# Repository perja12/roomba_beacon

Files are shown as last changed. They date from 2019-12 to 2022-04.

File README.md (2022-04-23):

# IR Beacon for Roomba

Quick links: [Schematic](https://perja12.github.io/roomba_beacon/kicad/ir_beacon/ir_beacon.pdf) | [Interactive BOM](https://perja12.github.io/roomba_beacon/kicad/ir_beacon/bom/ibom.html)

This project describes an IR beacon that can be used with certain Roomba vacuum cleaners. The beacon can be used to prevent the vacuum cleaner from entering a room or other off-limit zones. The vacuum cleaner will simply turn around when it receives the infrared light emitted from the beacon.

The project is inspired by a similar project from http://gregthielen.me/blogstuff/2017/06/27/roomba-virtual-wall/ and the timings for IR LED is taken directly from that page.

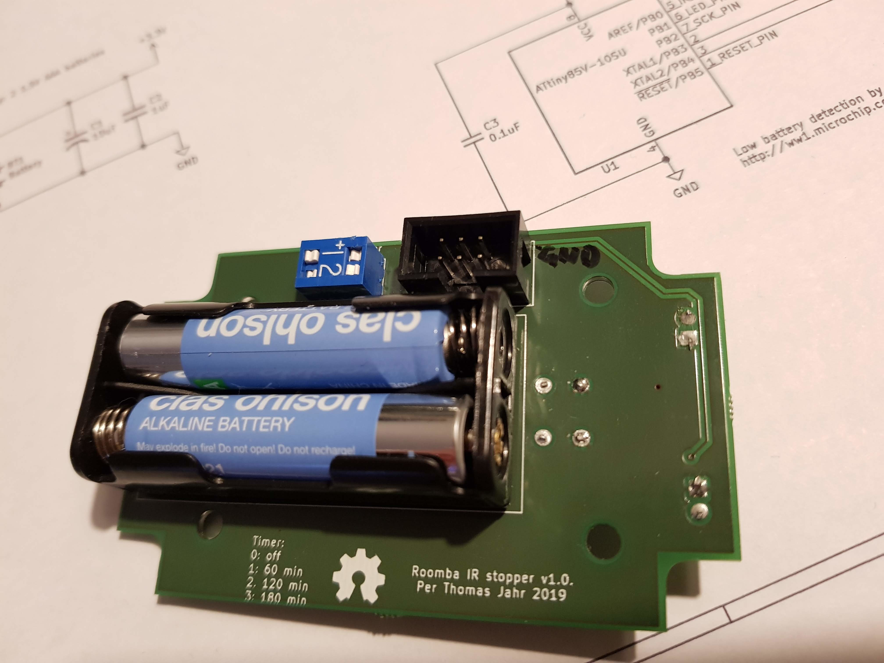
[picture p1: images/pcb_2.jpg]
PCB side 2


## Design

The circuit itself is simple enough; when the push button is pressed, the IR LED will flash in a given pattern. To save battery the duration is limited to one hour (configurable). In addition there is a green indicator LED that will flash once when the device is turned on and twice when turned off.

An ATtiny85V is used without any voltage regulator as it can operate with a voltage from 1.8 to 5.5V. The device is powered by two AAA alkaline batteries and the battery holder is soldered to the PCB. As the ATtiny85 have maximum current of 40 mA per pin and the IR LED (Vishay TSAL4000) has a forward current of 100 mA, we will need a transistor (MMBT3904) to switch the IR LED.

# Power consumption

There are two modes of operation:

1) Sleep mode: the IR LED is off and the MCU is in deep sleep. The current consumption is a couple of uA.

2) The average current consumption during active mode (when blinking the IR LED) is about 3.3 mA and can be lowered by using SLEEP_IDLE to save power and wake up when 132 ms have passed.

# Push button on/off switch

The circuit uses a power latch implemented by using special instructions that skips resetting a particular variable to zero during reset (see the _power_ variable in the code).  The push button is connected to the RESET pin and when pressed it will reset the MCU. The setup function toggles the _power_ variable and the circuit either goes to sleep or starts blinking the LED. With such a design it is important to have low sleep current. The solution is described here: http://www.technoblogy.com/show?VOO.

# Configurable on-duration

Depending on the route the vacuum cleaner chooses one can decide how many hours the device will be on. The user can configure this by setting two DIP switches. The duration is measured by using the number of milliseconds since the device was reset. The accuracy of this timer is not very good and can be off by several minutes. But for this purpose it works well enough.

# Detect low battery (not implemented)

On start up the indicator LED will blink rapidly if it is time to replace the batteries (around 2V). This is implemented by setting the internal reference voltage as ADC input and the target VCC as the ADC reference. The solution is described in this application note from Microchip: http://ww1.microchip.com/downloads/en/Appnotes/00002447A.pdf

# How to build

Install the ATTinyCore and use the following settings in the Arduino IDE

* Uses ATTinyCore: https://github.com/SpenceKonde/ATTinyCore
* 8 MHz internal clock
* B.O.D. disabled to save power

There is also a Makefile that uses [arduino-cli](https://www.arduino.cc/pro/cli).

# Enclosure

The PCB is designed so that it fits the Hammond 1591 ABS multipurpose enclosure and can be mounted directly without any standoffs. Only three additional holes are needed. Using one of the transparent boxes makes it easy to see where to drill. Note that there is a slight angle on the sides so the box wont stand exactly at 90 degrees, but close enough.

# Improvements

List of improvements that can be done:

* Clean up the layout and make it more compact.
* Replace delay in code with timers.
* Blink the LED now and then to show that it is on.

# Images

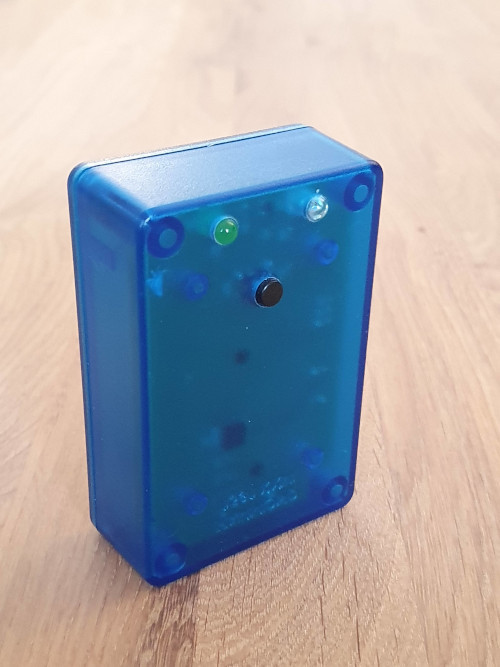
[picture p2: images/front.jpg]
Front

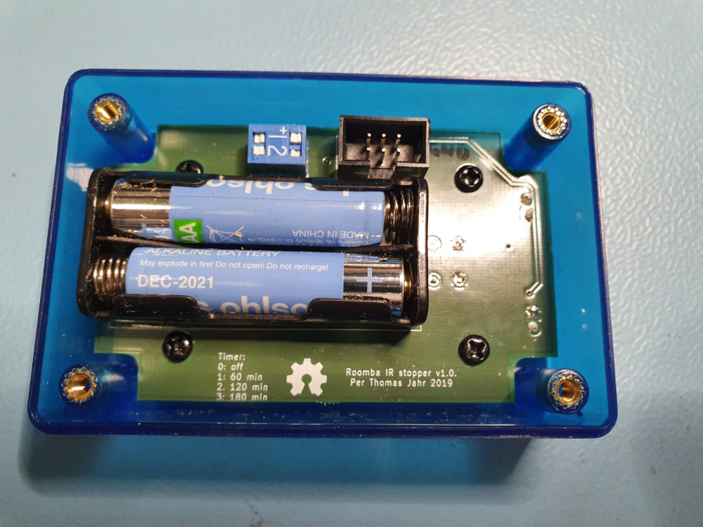
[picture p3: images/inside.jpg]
Inside enclousre

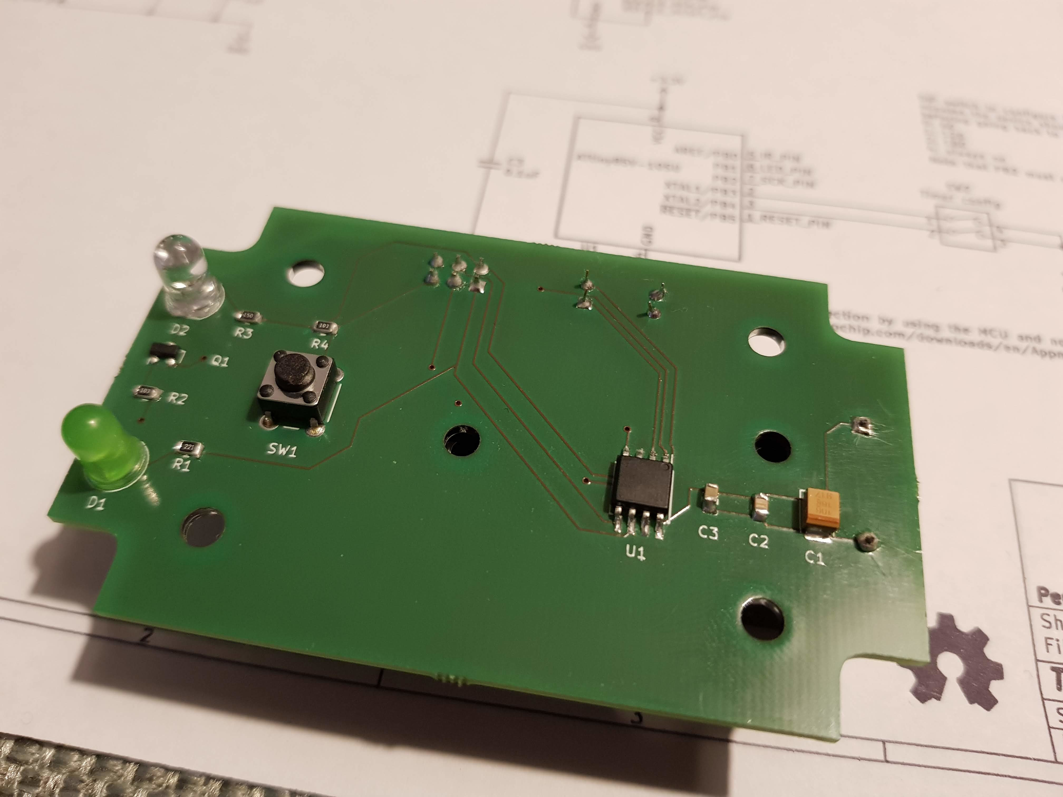
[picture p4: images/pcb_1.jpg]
PCB side 1


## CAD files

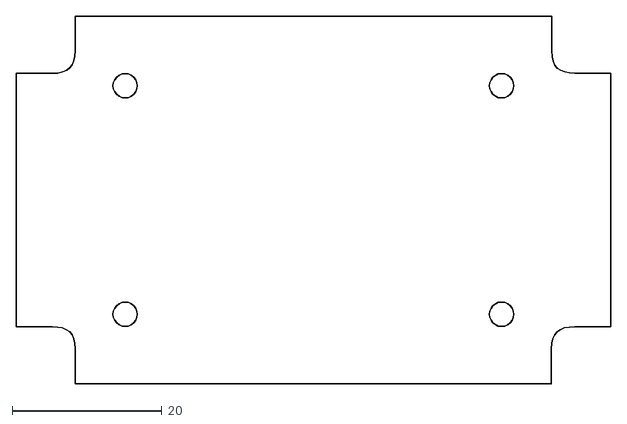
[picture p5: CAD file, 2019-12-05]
kicad/ir_beacon/1591_correct.dxf
79.4 x 49.1

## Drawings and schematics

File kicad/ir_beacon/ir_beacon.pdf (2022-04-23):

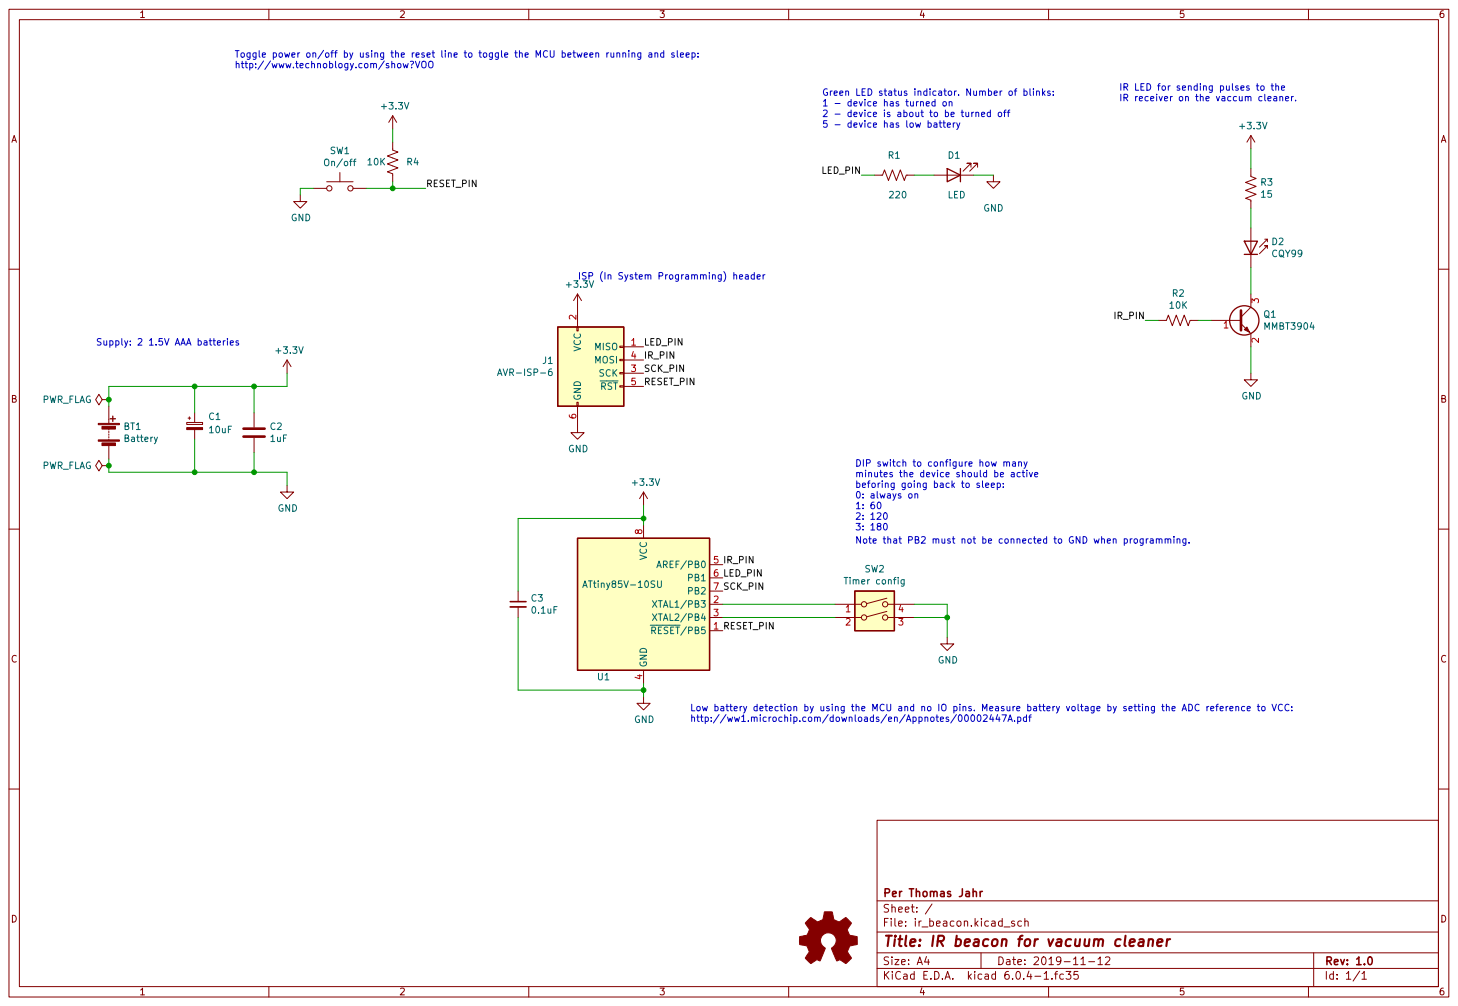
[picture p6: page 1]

Toggle power on/off by using the reset line to toggle the MCU between running and sleep:
http://www.technoblogy.com/show?VOO

IR receiver on the vaccum cleaner. Note that PB2 must not be connected to GND when programming.

IR LED for sending pulses to the

2 - device is about to be turned off 5 - device has low battery

ISP (In System Programming) header

2 SCK 3 MOSI 4 ~{RST} 5 GND

DIP switch to configure how many minutes the device should be active beforing going back to sleep:

Low battery detection by using the MCU and no IO pins. Measure battery voltage by setting the ADC reference to VCC:
http://ww1.microchip.com/downloads/en/Appnotes/00002447A.pdf

File: ir_beacon.kicad_sch Sheet: / Per Thomas Jahr

Id: 1/1 Title: IR beacon for vacuum cleaner

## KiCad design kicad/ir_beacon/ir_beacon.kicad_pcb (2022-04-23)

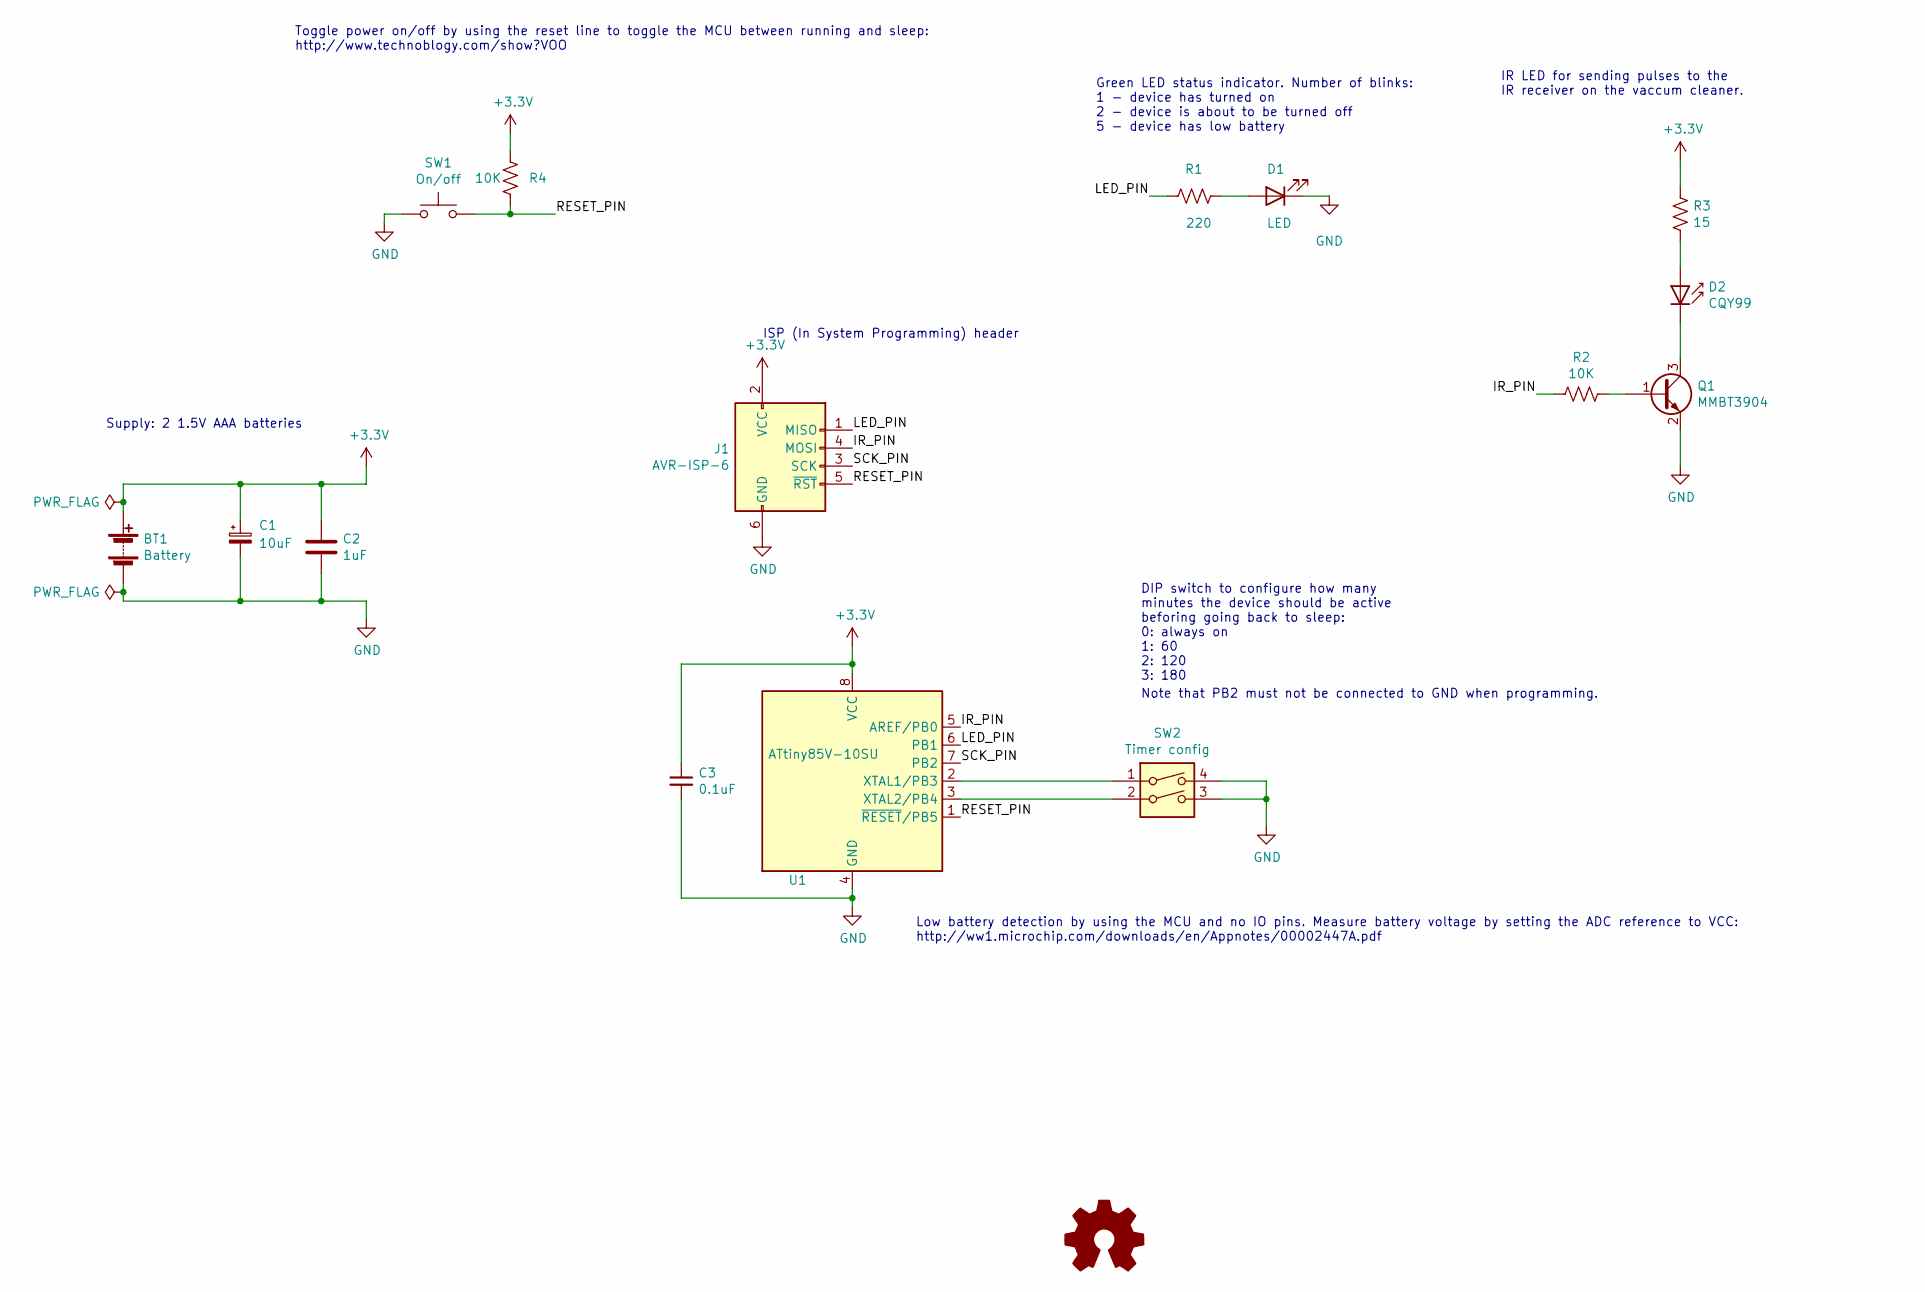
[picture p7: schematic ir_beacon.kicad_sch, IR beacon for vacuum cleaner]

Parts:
BT1: Battery; BatteryHolder_Keystone_2468_2xAAA
C1: 10uF; CP_EIA-6032-28_Kemet-C_Pad2.25x2.35mm_HandSolder
C2: 1uF; C_0805_2012Metric
C3: 0.1uF; C_0805_2012Metric
D1: LED; LED_D5.0mm
D2: CQY99; LED_D5.0mm_IRGrey
J1: AVR-ISP-6; IDC-Header_2x03_P2.54mm_Vertical
Q1: MMBT3904; SOT-23
R1: 220; R_0805_2012Metric
R2, R4: 10K; R_0805_2012Metric
R3: 15; R_0805_2012Metric
SW1: On/off; SW_PUSH_6mm
SW2: Timer config; SW_DIP_SPSTx02_Slide_9.78x7.26mm_W7.62mm_P2.54mm
U1: ATtiny85V-10SU; SOIJ-8_5.3x5.3mm_P1.27mm

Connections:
+3V3: BT1.1 (+), C1.1, C2.1, C3.1, J1.2 (VCC), R3.1, R4.1, U1.8 (VCC)
/IR_PIN: J1.4 (MOSI), R2.1, U1.5 (AREF/PB0)
/LED_PIN: J1.1 (MISO), R1.1, U1.6 (PB1)
/RESET_PIN: J1.5 (~RST), R4.2, SW1.2, U1.1 (~RESET/PB5)
/SCK_PIN: J1.3 (SCK), U1.7 (PB2)
GND: BT1.2 (-), C1.2, C2.2, C3.2, D1.1 (K), J1.6 (GND), Q1.2 (E), SW1.1, SW2.3, SW2.4, U1.4 (GND)
unnamed: D1.2 (A), R1.2
unnamed: D2.1 (K), Q1.3 (C)
unnamed: D2.2 (A), R3.2
unnamed: Q1.1 (B), R2.2
unnamed: SW2.1, U1.2 (XTAL1/PB3)
unnamed: SW2.2, U1.3 (XTAL2/PB4)

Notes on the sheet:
ISP (In System Programming) header
Low battery detection by using the MCU and no IO pins. Measure battery voltage by setting the ADC reference to VCC: http://ww1.microchip.com/downloads/en/Appnotes/00002447A.pdf
Note that PB2 must not be connected to GND when programming.
Toggle power on/off by using the reset line to toggle the MCU between running and sleep: http://www.technoblogy.com/show?VOO
DIP switch to configure how many minutes the device should be active beforing going back to sleep: 0: always on 1: 60 2: 120 3: 180
Green LED status indicator. Number of blinks: 1 - device has turned on 2 - device is about to be turned off 5 - device has low battery
Supply: 2 1.5V AAA batteries
IR LED for sending pulses to the IR receiver on the vaccum cleaner.

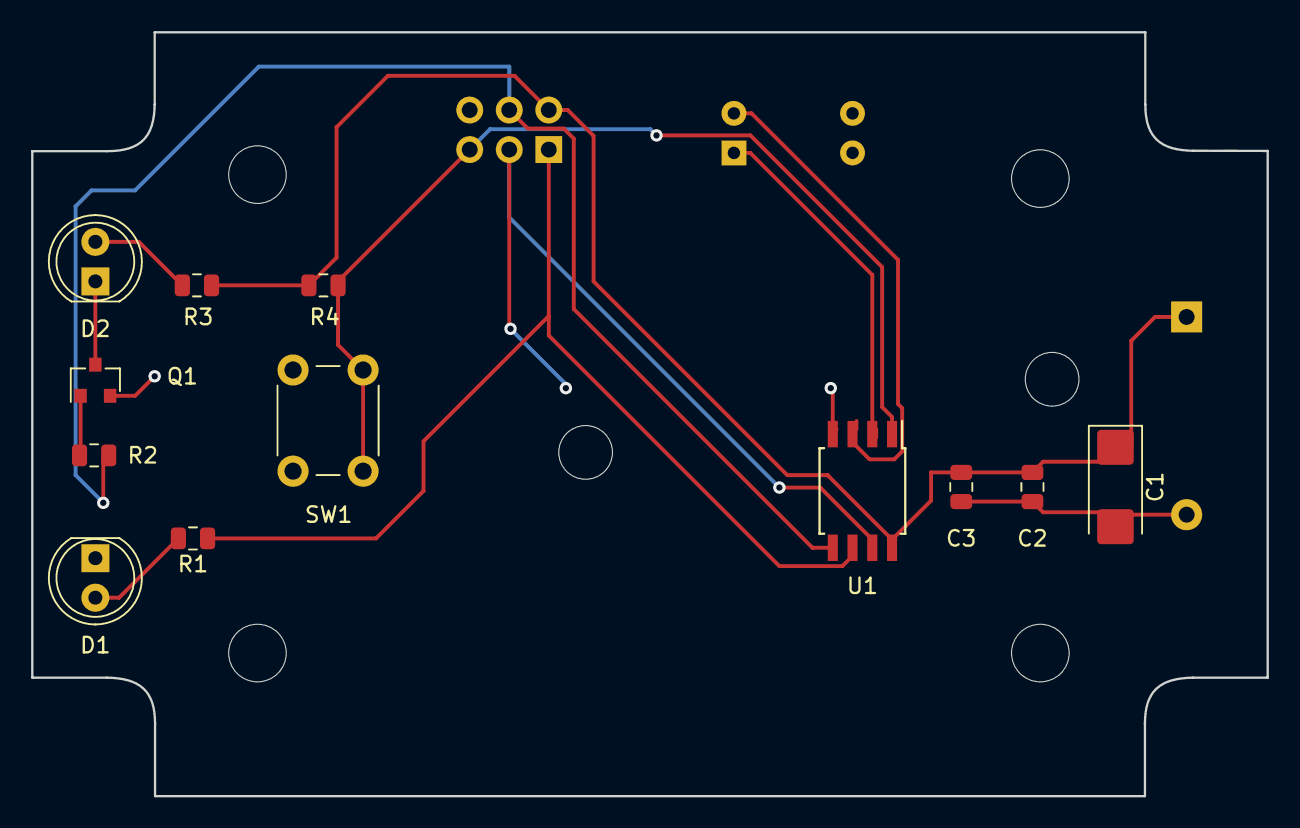
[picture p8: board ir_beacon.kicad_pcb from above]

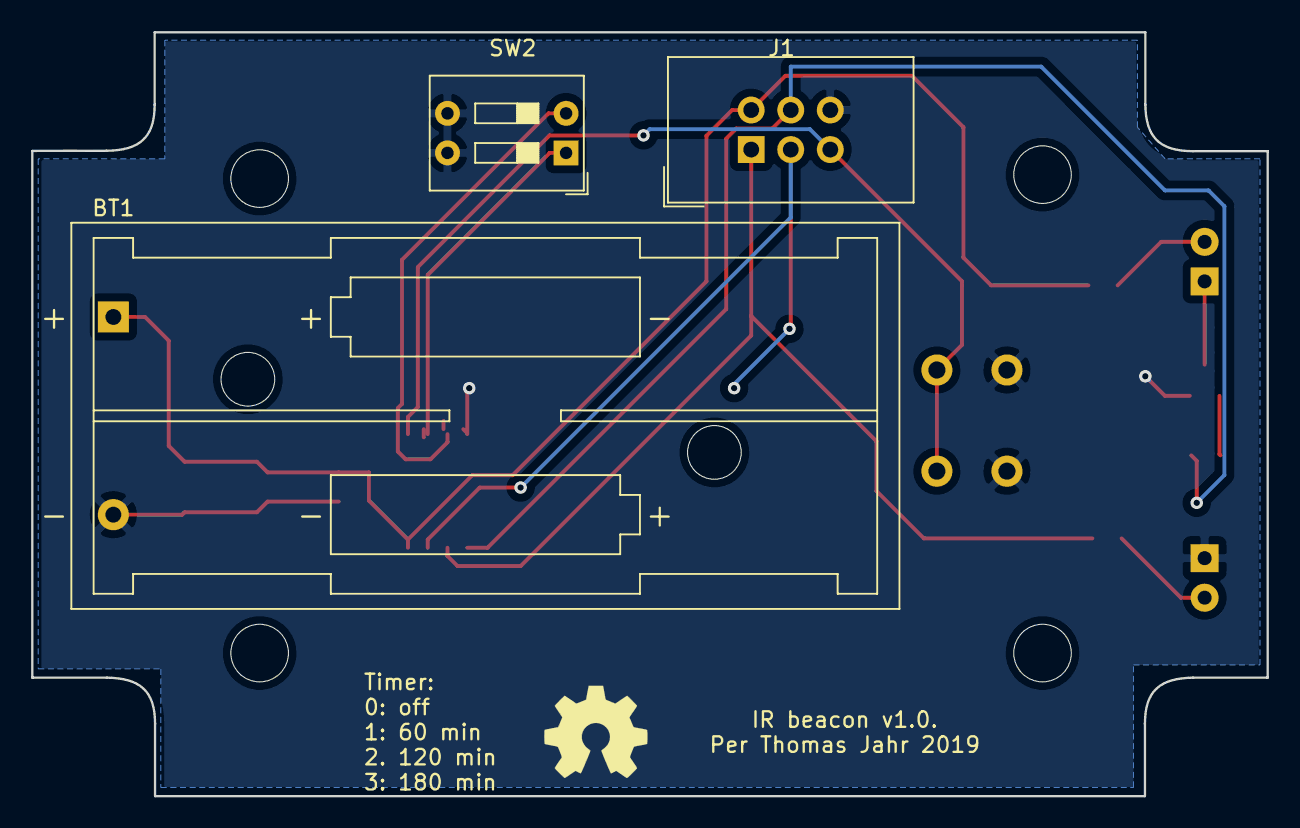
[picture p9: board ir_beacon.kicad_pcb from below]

Board: 2 copper layers, 79.4 x 49.1 mm, 15 parts (3 on the bottom side), 12 nets.

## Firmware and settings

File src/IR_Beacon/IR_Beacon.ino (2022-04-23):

#include <avr/sleep.h>
#include <avr/power.h>
#include <stdint.h>

#define BURST_ON                        500        // Burst on duration (uSec)
#define BURST_OFF                       7500       // Burst off duration (uSec)
#define BURST_COUNT                     3          // How many IR bursts to send
#define MINUTE_MILLIS                   60000

// Avoid initiating the power variable when resetting the MCU
// Pull reset pin low with push button for toggling power.
volatile uint8_t power __attribute__ ((section (".noinit")));

const int IRledPin = 0;
const int ledPin = 1;
const int dipPin1 = 4;
const int dipPin2 = 3;

uint32_t start_time;
uint8_t timer_config;

const uint32_t on_duration_ms[4] = {
    UINT32_MAX,
    60 * MINUTE_MILLIS,
    120 * MINUTE_MILLIS,
    180 * MINUTE_MILLIS
};

void setup() {
    set_sleep_mode(SLEEP_MODE_PWR_DOWN);
    pinMode(IRledPin, OUTPUT);
    pinMode(ledPin, OUTPUT);
    pinMode(dipPin1, INPUT_PULLUP);
    pinMode(dipPin2, INPUT_PULLUP);
    timer_config = (digitalRead(dipPin1) << 1) | digitalRead(dipPin2);

    // Turn off ADC to save power.
    ADCSRA &= ~ bit(ADEN);
    power_adc_disable();

    toggle_power();
    if (power == 0) {
        blink(2);
        go_to_sleep();
    } else {
        blink(1);
    }

    start_time = millis();
}

void loop() {
    send_ir_code();
    delay(132);

    // Turn everything off after the configured duration. This will
    // put the MCU in sleep mode and the reset button must be pushed
    // to turn it on again.
    if (millis() - start_time > on_duration_ms[timer_config]) {
        blink(2);
        toggle_power();
        go_to_sleep();
    }
}

void blink(int blinks) {
  for (int i = 0; i < blinks; i++) {
    digitalWrite(ledPin, HIGH);
    delay(150);
    digitalWrite(ledPin, LOW);
    delay(150);
  }
}

void toggle_power() {
  power = !power;
}

void go_to_sleep() {
    // Set the dip pins to INPUT to save power.
    pinMode(dipPin1, INPUT);
    pinMode(dipPin2, INPUT);

    // Power off ADC, Timer 0 and 1, serial interface.
    power_all_disable();
    sleep_enable();
    sleep_cpu();

    // Power everything back on.
    sleep_disable();
    power_all_enable();
}

void ir(long microsecs) {
  while (microsecs > 0) {
    digitalWrite(IRledPin, HIGH);
    delayMicroseconds(10);
    digitalWrite(IRledPin, LOW);
    delayMicroseconds(10);
    microsecs -= 26;
  }
}

void send_ir_code() {
  for (int i = 0; i < BURST_COUNT; i++) {
    ir(BURST_ON);
    delayMicroseconds(BURST_OFF);
  }
}

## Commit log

2019-12-05 Initial commit.
    [1591_correct.dxf, roomba_beacon.kicad_pcb, roomba_beacon.sch]
2019-12-16 Initial commit of Arduino sketch for beacon. Uses 3.3 mA in active mode.
2020-01-22 Rename files and update README.
    [1591_correct.dxf, ir_beacon.kicad_pcb, ir_beacon.sch]
2022-04-23 Cleanup a bit, add images and convert to KiCAD 6.
    [ir_beacon.kicad_pcb, ir_beacon.kicad_sch, ir_beacon.sch]
2022-04-23 Add PDF of schematic.
